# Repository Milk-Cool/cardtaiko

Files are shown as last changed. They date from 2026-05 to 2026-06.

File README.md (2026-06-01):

# card::taiko
osu!taiko simulator in a card form-factor!

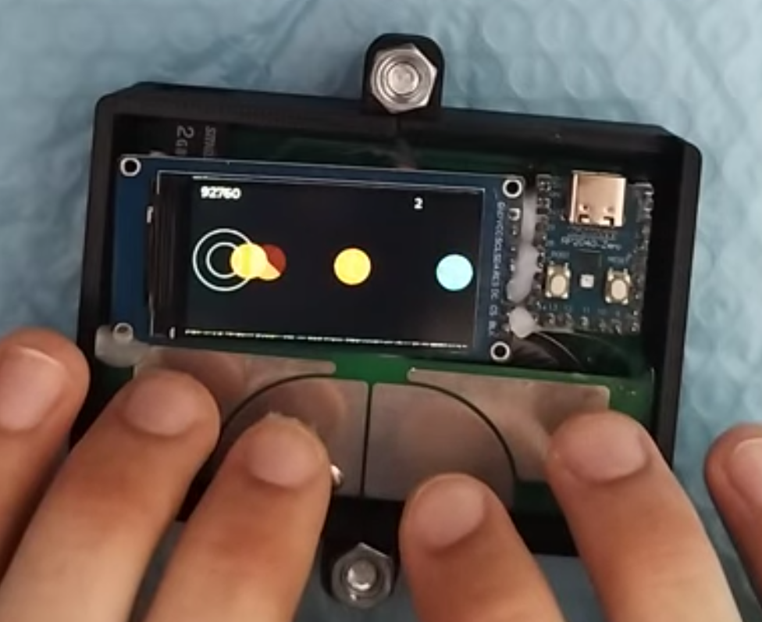
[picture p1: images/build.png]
card::taiko IRL


## what this is
this is an RP2040-Zero based device that is made for simulating osu!taiko as closely as i was able to make it. it comes with capacitive touch buttons specifically shaped for taiko, a 320x170 display, an SD card reader, a speaker and a battery. you can also emulate a keyboard to play taiko-based games on your PC.

## how do i use it?
you'll have to build one yourself!! you can see `bom.xml` for the list of parts, and all the PCBs and modelsn as well as the firmware can also be found in this repository. then, you can convert and upload songs to an sd card using the [online tool](https://milk-cool.github.io/cardtaiko/). you have to put the songs in `/taiko` on the SD card. then, boot up the device, select your song and have fun!! (you can pause at any time by pressing BOOTSEL on the board.)

for navigation, you can use the outer buttons to switch between options, the inner left one to go back and the inner right one to select.

### building it
there are a few unmarked headers on the pcb. the one closest to the RP2040-Zero is where the display goes, the one in the upper left corner is for the SD card reader, and the four small ones all around the bottom part are where the 1x1 headers go in for the capacitive touch board. speaking of which, you also have to solder in 4 1MOhm resistors near the pins so that capactive touch works.

> important: see the touch board to make sure everything lines up!!

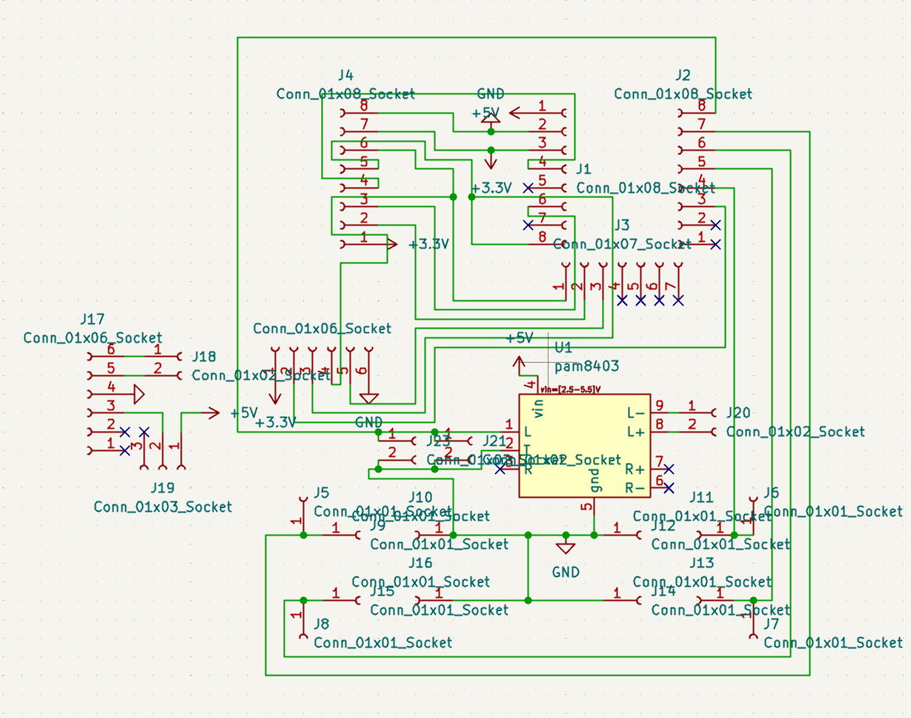
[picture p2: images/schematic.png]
the schematic

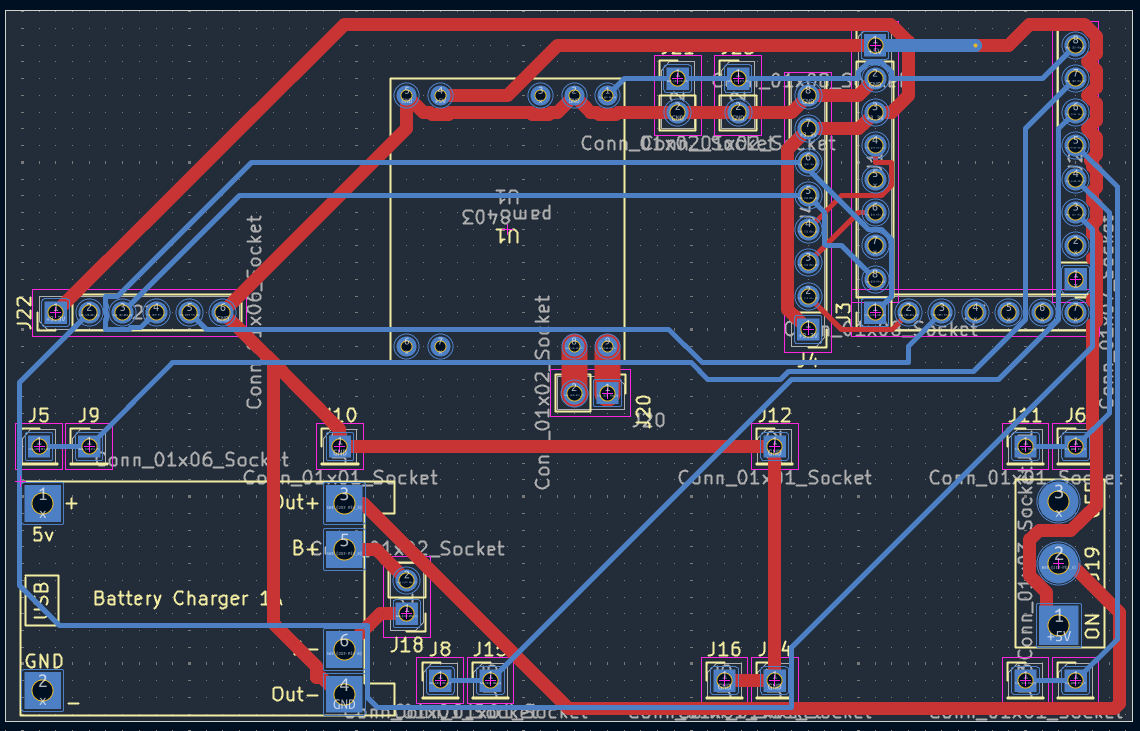
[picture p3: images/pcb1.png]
the main PCB

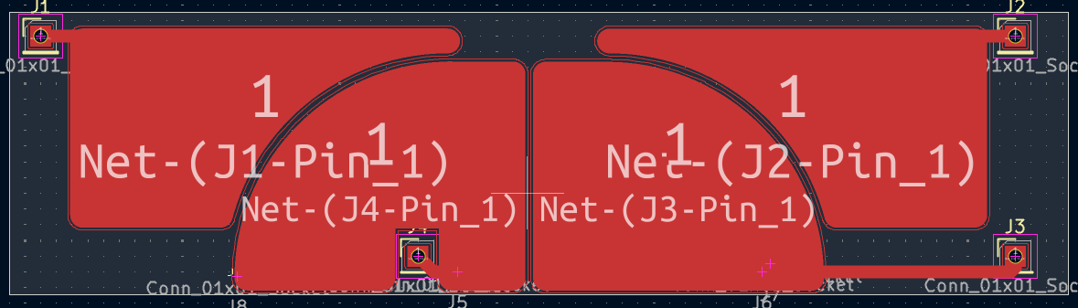
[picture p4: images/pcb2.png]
the touch PCB


### using the website
the interface is very simple: upload your .osz files, wait for the button to become active (that means that [ffmpeg](https://ffmpeg.org/) has loaded) and click convert!! evrything happens in your browser so it shouldn't take too long to finish.

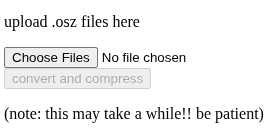
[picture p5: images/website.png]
the website UI


## why this was made
i am a huge fan of both taiko no tatsujin and osu!taiko, and also the [cardputer](https://shop.m5stack.com/products/m5stack-cardputer-adv-version-esp32-s3), which is why i decided it might be a fun idea to make a device that would let you play taiko on the go. and i also thought people might find the idea interesting as well :D

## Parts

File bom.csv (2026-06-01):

Product name | Product link | Product cost | Product amount | Notes
1 MOhm resistor | https://www.aliexpress.us/item/3256811699109203.html | $0.1 | 4 | Link leads to listing with 100 pieces available only. Price specified per unit; it is $0.99 to buy 100 pcs.
800 mAh lithium-ion battery | https://www.aliexpress.us/item/3256809268727485.html | $5.90 | 1
320x170 ST7789-based display | https://www.aliexpress.us/item/3256809447261733.html | $9.26 | 1 | w/ headers
RP2040-Zero board | https://www.aliexpress.us/item/3256806910625941.html | $5.08 | 1 | w/ headers
6-pin microSD card reader module | https://www.aliexpress.us/item/3256806810831719.html | $2.43 | 1 | Despite the seller saying it's a "Mini SD card module" it is not. Order that one.
0.1 uF ceramic capactior | https://www.aliexpress.us/item/3256809085304078.html | $0.02 | 1 | Link leads to listing with 100 pieces available only. Price specified per unit; it is $2.01 to buy 100 pcs.
10 uF electrolytic capactior | https://www.aliexpress.us/item/3256806406676171.html | $0.04 | 1 | Link leads to listing with 50 pieces available only. Price specified per unit; it is $2.16 to buy 50 pcs.
7-pin female headers | https://www.aliexpress.us/item/2255801012106911.html | $0.16 | 1 | Link leads to listing with 10 pieces available only. Price specified per unit; it is $1.60 to buy 10 pcs.
8-pin female headers | https://www.aliexpress.us/item/2255801012106911.html | $0.17 | 3 | Link leads to listing with 10 pieces available only. Price specified per unit; it is $1.65 to buy 10 pcs.
4-pin female headers | https://www.aliexpress.us/item/2255801012106911.html | $0.14 | 1 | Needs to be seprated into 4 1-pin headers. Link leads to listing with 10 pieces available only. Price specified per unit; it is $1.43 to buy 10 pcs.
4-pin male headers | https://www.aliexpress.us/item/3256809915878159.html | $0.14 | 1 | Needs to be seprated into 4 1-pin headers. Link leads to listing with 10 pieces available only. Price specified per unit; it is $1.35 to buy 10 pcs.
PAM8403 audio module | https://www.aliexpress.us/item/2255799876757727.html | $1.10 | 1
TP4056 power supply module | https://www.aliexpress.us/item/3256806796593467.html | $1.77 | 1
4ohm 3W speaker | https://www.aliexpress.us/item/2251832673662858.html | $0.81 | 1 | Link leads to listing with 5 pieces available only. Price specified per unit; it is $4.02 to buy 5 pcs.
1P2T switch | https://www.aliexpress.us/item/3256809760123375.html | $0.10 | 1 | Link leads to listing with 20 pieces available only. Price specified per unit; it is $2.00 to buy 20 pcs.

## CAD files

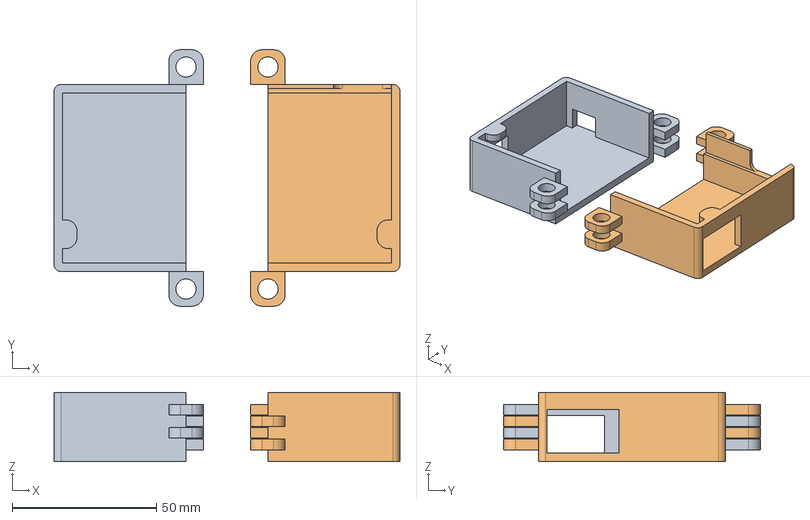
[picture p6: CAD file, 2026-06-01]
case/cardtaiko.step
120.0 x 89.0 x 24.0 mm

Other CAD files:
case/cardtaiko.FCStd
case/cardtaiko.obj

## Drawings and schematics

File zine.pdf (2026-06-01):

# card::taiko

## a credit card-sized osu!taiko

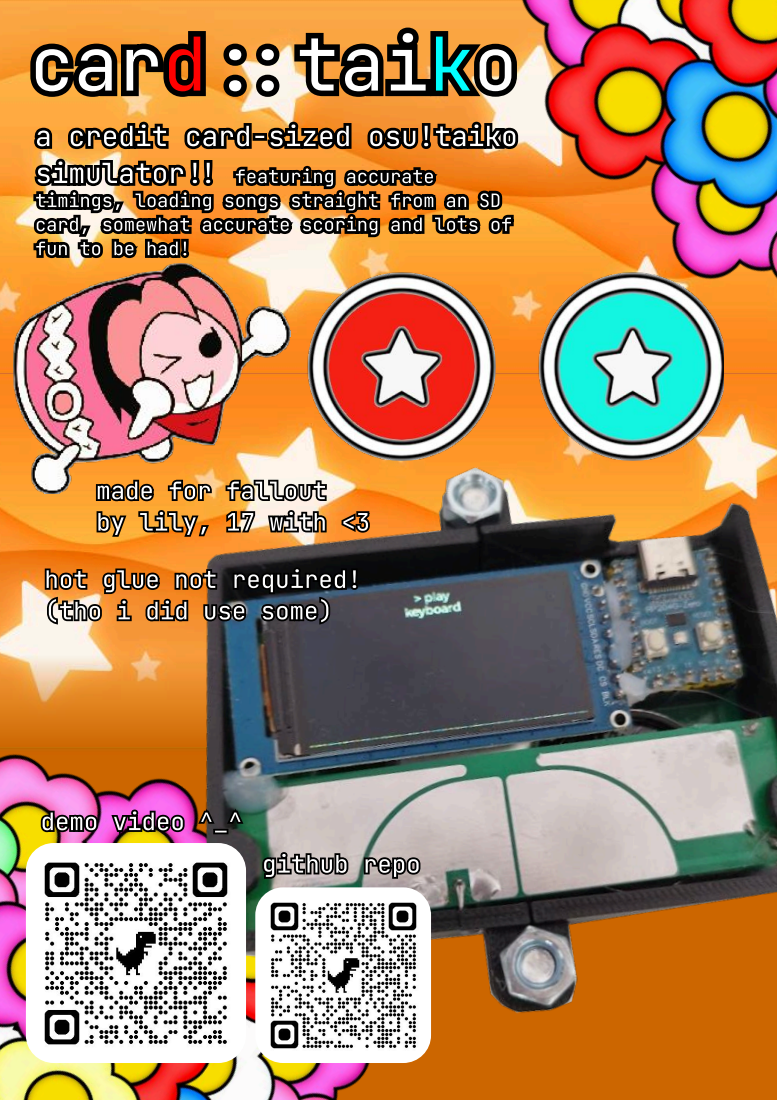
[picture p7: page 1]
demo video ^_^; github repo

simulator!! featuring accurate

timings, loading songs straight from an SD
card, somewhat accurate scoring and lots of
fun to be had!

made for fallout
by lily, 17 with <3

hot glue not required!
(tho i did use some)

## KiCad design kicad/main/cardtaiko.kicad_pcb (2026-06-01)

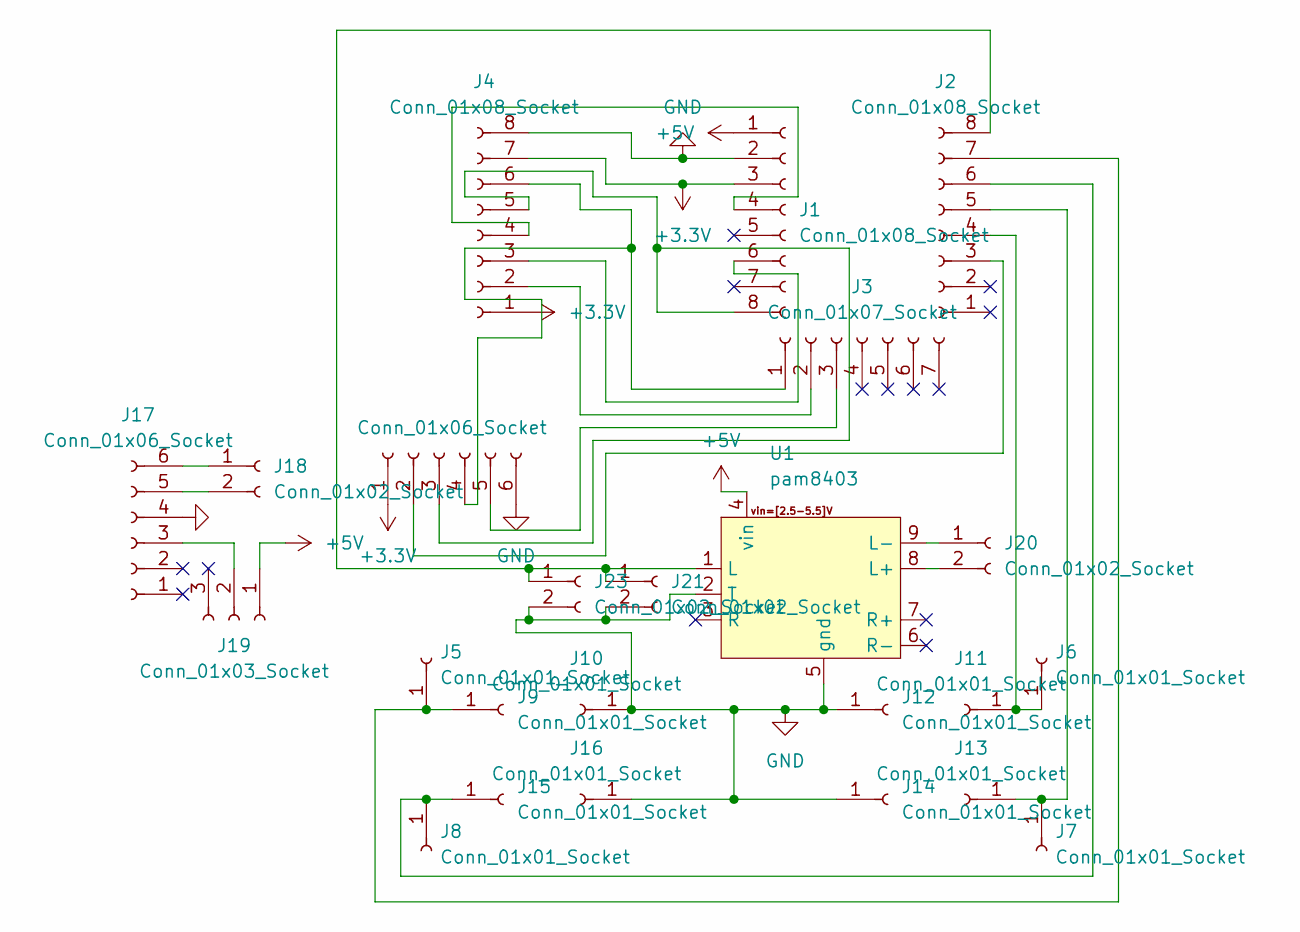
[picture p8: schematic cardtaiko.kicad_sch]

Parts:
J1, J2, J4: Conn_01x08_Socket; PinHeader_1x08_P2.54mm_Vertical
J3: Conn_01x07_Socket; PinHeader_1x07_P2.54mm_Vertical
J5, J6, J7, J8, J9, J10, J11, J12, J13, J14, J15, J16: Conn_01x01_Socket; PinHeader_1x01_P2.54mm_Vertical
J17: Conn_01x06_Socket; TP4056-18650
J18, J20, J21, J23: Conn_01x02_Socket; PinHeader_1x02_P2.54mm_Vertical
J19: Conn_01x03_Socket; 1p2t
J22: Conn_01x06_Socket; PinHeader_1x06_P2.54mm_Vertical
U1: pam8403

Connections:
+3.3V: J1.3, J4.1, J4.7, J22.1
+5V: J1.1, J19.1, U1.4 (vin)
GND: J1.2, J4.8, J10.1 (Pin_1_1), J12.1 (Pin_1_1), J14.1 (Pin_1_1), J16.1 (Pin_1_1), J17.4, J21.2, J22.6, J23.2, U1.2 (T), U1.5 (gnd)
unnamed: J1.4, J4.4
unnamed: J1.6, J4.3
unnamed: J1.8, J4.5, J22.3
unnamed: J2.3, J22.2
unnamed: J2.7, J5.1 (Pin_1_1), J9.1 (Pin_1_1)
unnamed: J2.8, J21.1, J23.1, U1.1 (L)
unnamed: J3.2, J4.2
unnamed: J2.4, J6.1 (Pin_1_1), J11.1 (Pin_1_1)
unnamed: J2.5, J7.1 (Pin_1_1), J13.1 (Pin_1_1)
unnamed: J2.6, J8.1 (Pin_1_1), J15.1 (Pin_1_1)
unnamed: J17.3, J19.2
unnamed: J17.5, J18.2
unnamed: J17.6, J18.1
unnamed: J20.1, U1.9 (L-)
unnamed: J20.2, U1.8 (L+)
unnamed: J3.1, J4.6, J22.4
unnamed: J3.3, J22.5

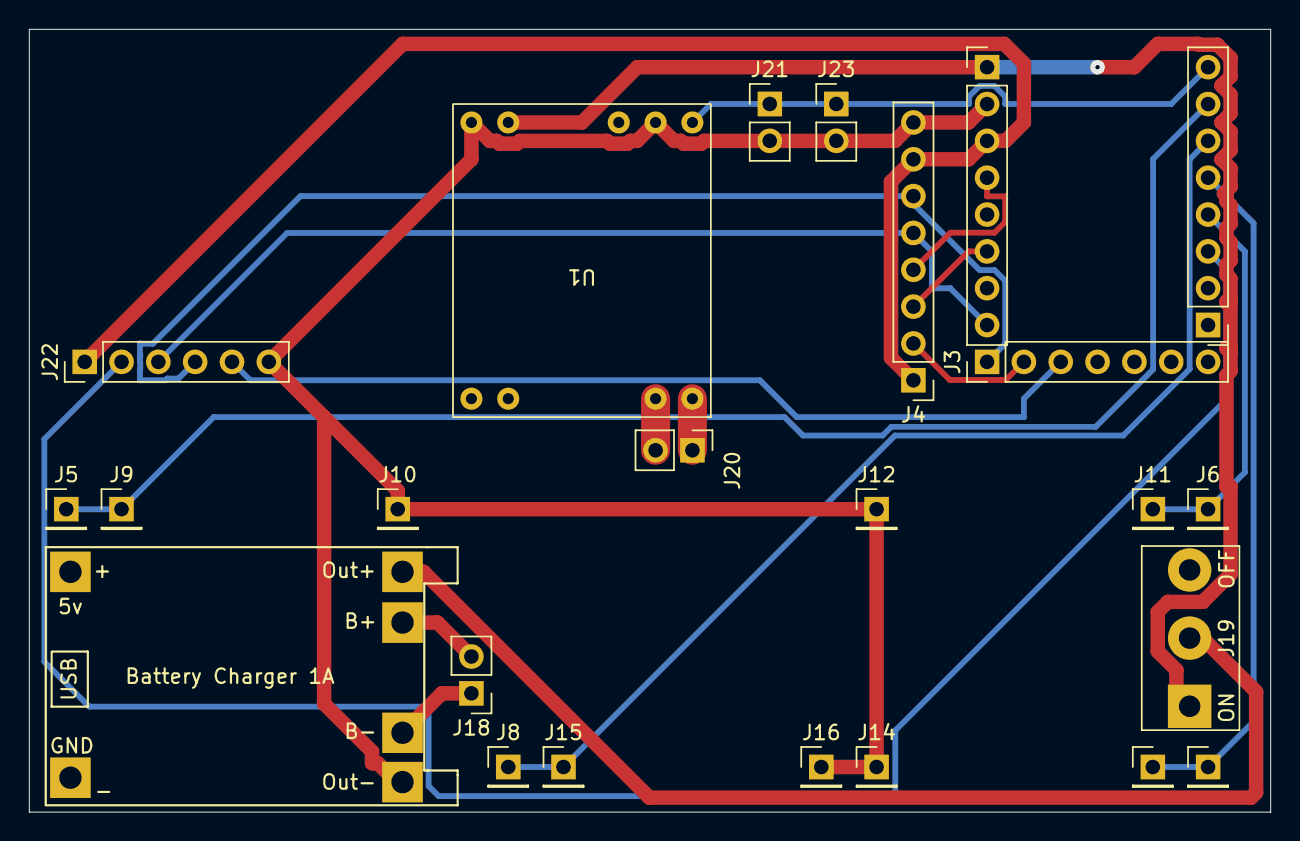
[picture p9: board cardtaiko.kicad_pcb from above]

Board: 2 copper layers, 85.6 x 54.0 mm, 24 parts (0 on the bottom side), 20 nets.

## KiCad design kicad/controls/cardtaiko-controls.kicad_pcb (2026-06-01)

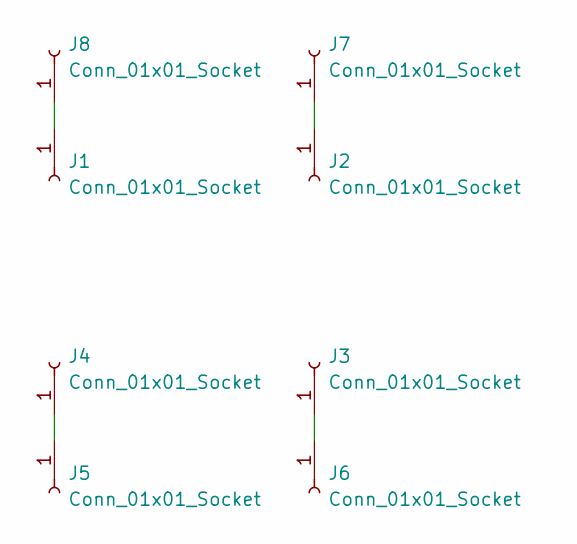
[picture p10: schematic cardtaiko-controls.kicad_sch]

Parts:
J1, J2, J3, J4: Conn_01x01_Socket; PinHeader_1x01_P2.54mm_Vertical
J5: Conn_01x01_Socket; Don Left
J6: Conn_01x01_Socket; Don Right
J7: Conn_01x01_Socket; Kat Right
J8: Conn_01x01_Socket; Kat Left

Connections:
unnamed: J1.1 (Pin_1_1), J8.1 (Pin_1_1)
unnamed: J2.1 (Pin_1_1), J7.1 (Pin_1_1)
unnamed: J3.1 (Pin_1_1), J6.1 (Pin_1_1)
unnamed: J4.1 (Pin_1_1), J5.1 (Pin_1_1)

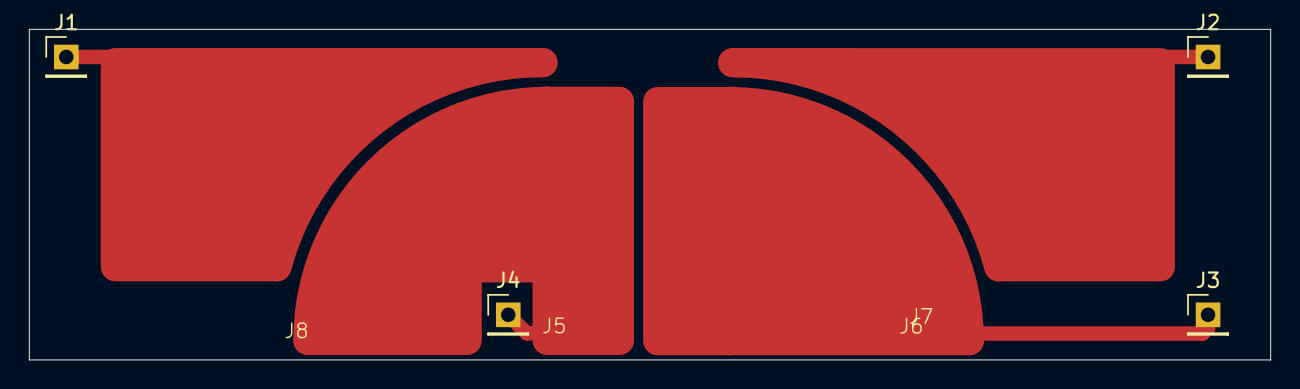
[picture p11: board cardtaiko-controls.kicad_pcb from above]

Board: 2 copper layers, 85.6 x 22.8 mm, 8 parts (0 on the bottom side), 4 nets.

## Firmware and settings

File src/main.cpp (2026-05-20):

#include <Arduino.h>
#include <LovyanGFX.hpp>
#include <SPI.h>
#include "lvcfg.h"
#include <lvgl.h>
#include "maps.h"
#include "input.h"
#include "en.h"
#include "audio.h"
#include <NeoPixelConnect.h>
#include <Keyboard.h>

#define W 320
#define H 170

static lv_disp_draw_buf_t draw_buf;
static lv_color_t buf[2][W * 10]; // what.

static bool simple_rendering = false;

static NeoPixelConnect p(16, 1);

class LGFX : public lgfx::LGFX_Device {
    lgfx::Panel_ST7789 _panel_instance;
    lgfx::Bus_SPI _bus_instance;

public:
    // https://garrysblog.com/2025/11/10/lovyangfx-display-config-code-ili9341-gc9a01-and-st7789-displays/
    LGFX() {
        {
            auto cfg = _bus_instance.config();
            cfg.spi_host = 1;
            cfg.spi_mode = 0;
            cfg.freq_write = 640000000; // how does this work???
            cfg.freq_read = 10000000;
            cfg.pin_sclk = 14;
            cfg.pin_mosi = 15;
            cfg.pin_miso = 12;
            cfg.pin_dc = 27;
            _bus_instance.config(cfg);
            _panel_instance.setBus(&_bus_instance);
        }
        {
            auto cfg = _panel_instance.config();
            cfg.pin_cs = 13;
            cfg.pin_rst = 29;
            cfg.pin_busy = -1;
            cfg.panel_width = H; // swapped bc display is rotated
            cfg.panel_height = W;
            cfg.offset_x = 34;
            cfg.offset_y = 0;
            cfg.offset_rotation = 0;
            cfg.dummy_read_pixel = 8;
            cfg.dummy_read_bits = 1;
            cfg.readable = false;
            cfg.invert = true;
            cfg.rgb_order = false;
            cfg.dlen_16bit = false;
            cfg.bus_shared = false;
            _panel_instance.config(cfg);
        }

        setPanel(&_panel_instance);
    }
};

LGFX tft = LGFX();

// https://github.com/lovyan03/LovyanGFX/blob/master/examples/Advanced/LVGL_PlatformIO/src/main.cpp#L17
void flush_gfx(lv_disp_drv_t* disp, const lv_area_t* area, lv_color_t* color_p) {
    if(tft.getStartCount() == 0)
        tft.startWrite();
    // hah. screw you google. screw you chatgpt. rgb565_t instead of swap565_t was the fix. and not even uint16_t. not even anything in lvcfg.h. hahah.
    tft.pushImageDMA(area->x1, area->y1, area->x2 - area->x1 + 1, area->y2 - area->y1 + 1, (lgfx::rgb565_t*)&color_p->full);
    tft.endWrite();
    lv_disp_flush_ready(disp);
}

static String filename(String path) {
    auto idx = path.lastIndexOf('/');
    if(idx == path.length() - 1) idx = path.substring(0, path.length() - 1).lastIndexOf('/');
    return path.substring(idx + 1);
}
static String diffname(String filename) {
    return filename.substring(filename.indexOf('[') + 1, filename.indexOf(']'));
}

static uint64_t game_start = 0;
static uint64_t pause_start;
static uint8_t menu_state = 0;
static bool use_diffname = false;
#define MENU_MAIN 0
#define MENU_LEVEL 1
#define MENU_DIFF 2
#define MENU_GAME 3
#define MENU_PAUSE 4
#define MENU_RESULTS 5
#define MENU_KEYBOARD 6
static std::vector<String> menu_options;
static unsigned menu_idx;
static String level_path;

Level lvl(""); // dummy level, we'll load the actual thing later on
lv_obj_t* score;
lv_obj_t* combo;
lv_obj_t* rating;
lv_obj_t* delta;
lv_obj_t* circles[2];
lv_obj_t* menu;
std::vector<lv_obj_t*> past;

static bool recalibrated = false;

static void menu_main() {
    menu_state = MENU_MAIN;
    menu_options.clear();
    menu_idx = 0;

    menu_options.push_back("play");
    menu_options.push_back("keyboard");
    // TODO
}
static void menu_level() {
    menu_state = MENU_LEVEL;
    menu_options.clear();
    menu_idx = 0;

    esd();
    maps_init();
    auto levels = maps_list();
    for(auto level : levels)
        menu_options.push_back(filename(level));
    maps_deinit();
    etft();
}
static void menu_diff() {
    menu_state = MENU_DIFF;
    menu_options.clear();
    menu_idx = 0;

    use_diffname = true;

    esd();
    maps_init();
    auto diffs = difficulty_list(level_path);
    for(auto diff : diffs)
        menu_options.push_back(filename(diff));
    maps_deinit();
    etft();
}
static void game_hide() {
    lv_obj_set_style_opa(score, LV_OPA_0, 0);
    lv_obj_set_style_opa(combo, LV_OPA_0, 0);
    lv_obj_set_style_opa(rating, LV_OPA_0, 0);
    lv_obj_set_style_opa(delta, LV_OPA_0, 0);
    lv_obj_set_style_opa(circles[0], LV_OPA_0, 0);
    lv_obj_set_style_opa(circles[1], LV_OPA_0, 0);
    lv_obj_set_style_opa(menu, LV_OPA_100, 0);
}
static void game_show() {
    lv_obj_set_style_opa(score, LV_OPA_100, 0);
    lv_obj_set_style_opa(combo, LV_OPA_100, 0);
    lv_obj_set_style_opa(rating, LV_OPA_100, 0);
    lv_obj_set_style_opa(delta, LV_OPA_100, 0);
    lv_obj_set_style_opa(circles[0], LV_OPA_100, 0);
    lv_obj_set_style_opa(circles[1], LV_OPA_100, 0);
    lv_obj_set_style_opa(menu, LV_OPA_0, 0);
}
static void menu_pause() {
    menu_state = MENU_PAUSE;
    menu_options.clear();
    menu_idx = 0;

    game_hide();
    menu_options.push_back("resume");
    menu_options.push_back("exit");

    for(auto x : past)
        lv_obj_del(x);
    past.clear();
}
static void menu_results() {
    menu_state = MENU_RESULTS;
    menu_options.clear();
    menu_idx = 0;

    game_hide();
    menu_options.push_back("GREAT: " + String(lvl.great));
    menu_options.push_back("OK: " + String(lvl.ok));
    menu_options.push_back("MISS: " + String(lvl.miss));
    menu_options.push_back("COMBO: " + String(lvl.combo));
    menu_options.push_back("MAX COMBO: " + String(lvl.maxcombo));
    menu_options.push_back("SCORE: " + String(lvl.score));
    menu_options.push_back("exit");

    for(auto x : past)
        lv_obj_del(x);
    past.clear();

    audio_stop();
}
static void menu_keyboard() {
    menu_state = MENU_KEYBOARD;
    menu_options.clear();
    menu_idx = 0;

    Keyboard.begin();
}
void setup() {
    // Serial.begin(115200); // no serial bc speaker

    audio_init();
    init_input();

    etft();
    tft.init();
    tft.setRotation(3);
    lv_init();
    lv_disp_draw_buf_init(&draw_buf, buf[0], buf[1], W * 10);

    // https://github.com/lovyan03/LovyanGFX/blob/master/examples/Advanced/LVGL_PlatformIO/src/main.cpp#L67
    static lv_disp_drv_t disp_drv;
    lv_disp_drv_init(&disp_drv);
    disp_drv.hor_res = W;
    disp_drv.ver_res = H;
    disp_drv.flush_cb = flush_gfx;
    disp_drv.draw_buf = &draw_buf;
    lv_disp_drv_register(&disp_drv);

    lv_obj_clear_flag(lv_scr_act(), LV_OBJ_FLAG_SCROLLABLE);
    lv_obj_set_style_bg_color(lv_scr_act(), lv_color_black(), 0);

    score = lv_label_create(lv_scr_act());
    lv_obj_set_x(score, 10);
    lv_obj_set_y(score, 0);
    lv_obj_set_style_text_color(score, lv_color_white(), 0);
    lv_label_set_text(score, "0");

    combo = lv_label_create(lv_scr_act());
    lv_obj_set_x(combo, 250);
    lv_obj_set_y(combo, 0);
    lv_obj_set_style_text_color(combo, lv_color_white(), 0);
    lv_label_set_text(combo, "0");

    rating = lv_label_create(lv_scr_act());
    lv_obj_set_x(rating, 15);
    lv_obj_set_y(rating, 17);
    lv_obj_set_style_text_align(rating, LV_TEXT_ALIGN_CENTER, 0);
    lv_obj_set_style_text_color(rating, lv_color_white(), 0);
    lv_obj_set_width(rating, 50);
    lv_label_set_text(rating, "");

    delta = lv_label_create(lv_scr_act());
    lv_obj_set_x(delta, 15);
    lv_obj_set_y(delta, 32);
    lv_obj_set_style_text_align(delta, LV_TEXT_ALIGN_CENTER, 0);
    lv_obj_set_style_text_color(delta, lv_color_white(), 0);
    lv_obj_set_width(delta, 50);
    lv_label_set_text(delta, "");

    menu = lv_label_create(lv_scr_act());
    lv_obj_set_x(menu, 0);
    lv_obj_set_y(menu, 0);
    lv_obj_set_style_text_align(menu, LV_TEXT_ALIGN_CENTER, 0);
    lv_obj_set_style_text_color(menu, lv_color_white(), 0);
    lv_obj_set_width(menu, W);
    lv_obj_set_height(menu, H);
    lv_label_set_text(menu, "");

    int j = 0;
    for(int i = 35; i >= 20; i -= 15) {
        lv_obj_t* circle = lv_obj_create(lv_scr_act());
        lv_obj_set_x(circle, 40 - i);
        lv_obj_set_y(circle, 170 / 2 - i);
        lv_obj_set_size(circle, 2 * i, 2 * i);
        lv_obj_set_style_radius(circle, LV_RADIUS_CIRCLE, 0);
        lv_obj_set_style_bg_color(circle, lv_color_black(), 0);
        lv_obj_set_style_bg_opa(circle, LV_OPA_COVER, 0);
        lv_obj_set_style_border_color(circle, lv_palette_main(LV_PALETTE_GREY), 0);
        lv_obj_set_style_border_width(circle, 2, 0);
        circles[j++] = circle;
    }

    menu_main();
    game_hide();
}
uint8_t last_mask = 0;
static void render_menu(uint8_t pressed) {
    if(check_input(pressed, INPUT_KAT_LEFT)) {
        if(menu_idx == 0) menu_idx = menu_options.size() - 1;
        else menu_idx--;
    } else if(check_input(pressed, INPUT_KAT_RIGHT)) {
        if(menu_idx == menu_options.size() - 1) menu_idx = 0;
        else menu_idx++;
    }

    unsigned start = (menu_idx / 10) * 10;
    std::vector<String> sel_options;
    for(unsigned i = start; i < menu_options.size() && i < start + 10; i++)
        sel_options.push_back(menu_options[i]);
    String o = "";
    for(int i = 0; i < sel_options.size(); i++)
        o += (i == menu_idx - start ? "> " : "") + (use_diffname ? diffname(sel_options[i]) : sel_options[i]) + "\n";
    lv_label_set_text(menu, o.c_str());
}
static void loop_main(uint8_t pressed) {
    render_menu(pressed);

    if(check_input(pressed, INPUT_DON_RIGHT)) {
        String& sel = menu_options[menu_idx];
        if(sel == "play") menu_level();
        else if(sel == "keyboard") menu_keyboard();
    }
}
static void loop_level(uint8_t pressed) {
    render_menu(pressed);

    if(check_input(pressed, INPUT_DON_RIGHT)) {
        String& sel = menu_options[menu_idx];
        level_path = "/taiko/" + sel;
        menu_diff();
    } else if(check_input(pressed, INPUT_DON_LEFT))
        menu_main();
}
static void loop_diff(uint8_t pressed) {
    render_menu(pressed);

    if(check_input(pressed, INPUT_DON_RIGHT)) {
        use_diffname = false;
        String& sel = menu_options[menu_idx];
        esd();
        maps_init();
        lvl = load_level(level_path + "/" + sel);
        maps_deinit();
        etft();
        audio_play(level_path + "/");
        game_start = 0;
        menu_state = MENU_GAME;
        recalibrated = false;
        game_show();
    } else if(check_input(pressed, INPUT_DON_LEFT)) {
        use_diffname = false;
        menu_level();
    }
}
static void loop_game(uint8_t pressed) {
    if(millis() < game_start) return;

    if(!recalibrated && millis() - game_start >= 150) {
        recalibrated = true;
        recalibrate_input();
    }

    if(check_input(pressed, INPUT_BOOTSEL)) {
        pause_start = millis();
        menu_pause();

        return;
    }

    lvl.btn(millis() - game_start, pressed);

    for(auto x : past)
        lv_obj_del(x);
    past.clear();
    auto cur = lvl.render(millis() - game_start);
    if(cur.fin) {
        lvl.fin();
        menu_results();
        return;
    }
    for(auto x : cur.objs) {
        int r = x.big ? 35 : 20;
        auto c = x.type & 8 ? LV_PALETTE_INDIGO : x.type & 2 ? LV_PALETTE_YELLOW : x.kat ? LV_PALETTE_CYAN : LV_PALETTE_RED;

        lv_obj_t* circle = lv_obj_create(lv_scr_act());
        lv_obj_set_x(circle, x.x - r);
        lv_obj_set_y(circle, 170 / 2 - r);
        lv_obj_set_size(circle, 2 * r + x.len, 2 * r);
        lv_obj_set_style_radius(circle, r, 0);
        lv_obj_set_style_bg_color(circle, lv_palette_main(c), 0);
        lv_obj_set_style_bg_opa(circle, simple_rendering ? LV_OPA_TRANSP : LV_OPA_COVER, 0);
        lv_obj_set_style_border_width(circle, simple_rendering ? 2 : 0, 0);
        lv_obj_set_style_border_color(circle, lv_palette_main(c), 0);
        past.push_back(circle);
    }
    
    auto rat = lvl.get_rating(millis() - game_start);
    lv_label_set_text(rating, rat.txt.c_str());
    lv_label_set_text(delta, rat.delta.c_str());
    lv_obj_set_style_text_opa(rating, rat.opacity * 255, 0);
    lv_obj_set_style_text_opa(delta, rat.opacity * 255, 0);

    lv_label_set_text(score, String(lvl.score).c_str());
    lv_label_set_text(combo, String(lvl.combo).c_str());
}
static void loop_pause(uint8_t pressed) {
    render_menu(pressed);

    if(check_input(pressed, INPUT_DON_RIGHT)) {
        String& sel = menu_options[menu_idx];
        if(sel == "exit") {
            audio_stop();
            menu_main();
        } else if(sel == "resume") {
            game_show();
            game_start += millis() - pause_start;
            menu_state = MENU_GAME;
            menu_options.clear();
        }
    }
}
static void loop_results(uint8_t pressed) {
    render_menu(pressed);

    if(check_input(pressed, INPUT_DON_RIGHT)) {
        String& sel = menu_options[menu_idx];
        if(sel == "exit") {
            delay(150); // lazy fix
            recalibrate_input();
            menu_main();
        }
    }
}
static void loop_keyboard(uint8_t held) {
    render_menu(0);

    if(check_input(held, INPUT_KAT_LEFT)) Keyboard.press('d');
    else Keyboard.release('d');
    if(check_input(held, INPUT_DON_LEFT)) Keyboard.press('f');
    else Keyboard.release('f');
    if(check_input(held, INPUT_DON_RIGHT)) Keyboard.press('j');
    else Keyboard.release('j');
    if(check_input(held, INPUT_KAT_RIGHT)) Keyboard.press('k');
    else Keyboard.release('k');
    if(check_input(held, INPUT_BOOTSEL)) {
        Keyboard.end();
        menu_main();
    }
}
uint64_t last = 0;
void loop() {
    if(menu_state == MENU_GAME) {
        audio_loop();
        if(game_start == 0) game_start = millis() + 10; // compensate for the audio offset
    }

    uint8_t mask = get_input();
    bool don = check_input(mask, INPUT_DON_LEFT) || check_input(mask, INPUT_DON_RIGHT);
    bool kat = check_input(mask, INPUT_KAT_LEFT) || check_input(mask, INPUT_KAT_RIGHT);
    // use 40 for dimmer led
    if(don && kat) p.neoPixelSetValue(0, 40, 40, 0, true);
    else if(kat) p.neoPixelSetValue(0, 0, 40, 40, true);
    else if(don) p.neoPixelSetValue(0, 40, 0, 0, true);
    else p.neoPixelSetValue(0, 0, 0, 0, true);

    uint8_t pressed = (mask ^ last_mask) & mask;
    // if(check_input(pressed, INPUT_DON_RIGHT)) Serial.println("DON_RIGHT");
    // if(check_input(pressed, INPUT_DON_LEFT)) Serial.println("DON_LEFT");
    // if(check_input(pressed, INPUT_KAT_RIGHT)) Serial.println("KAT_RIGHT");
    // if(check_input(pressed, INPUT_KAT_LEFT)) Serial.println("KAT_LEFT");
    // if(check_input(pressed, INPUT_BOOTSEL)) Serial.println("BOOTSEL");
    last_mask = mask;

    if(menu_state == MENU_MAIN)
        loop_main(pressed);
    else if(menu_state == MENU_LEVEL)
        loop_level(pressed);
    else if(menu_state == MENU_DIFF)
        loop_diff(pressed);
    else if(menu_state == MENU_GAME)
        loop_game(pressed);
    else if(menu_state == MENU_PAUSE)
        loop_pause(pressed);
    else if(menu_state == MENU_RESULTS)
        loop_results(pressed);
    else if(menu_state == MENU_KEYBOARD)
        loop_keyboard(mask);

    lv_refr_now(lv_disp_get_default());
    lv_timer_handler();
}

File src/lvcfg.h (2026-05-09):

/**
 * @file lv_conf.h
 * Configuration file for v8.3.0-dev
 */

/*
 * Copy this file as `lv_conf.h`
 * 1. simply next to the `lvgl` folder
 * 2. or any other places and
 *    - define `LV_CONF_INCLUDE_SIMPLE`
 *    - add the path as include path
 */

/* clang-format off */
#if 1 /*Set it to "1" to enable content*/

#ifndef LV_CONF_H
#define LV_CONF_H

#include <stdint.h>

/*====================
   COLOR SETTINGS
 *====================*/

/*Color depth: 1 (1 byte per pixel), 8 (RGB332), 16 (RGB565), 32 (ARGB8888)*/
#define LV_COLOR_DEPTH 16

/*Swap the 2 bytes of RGB565 color. Useful if the display has an 8-bit interface (e.g. SPI)*/
#define LV_COLOR_16_SWAP 0

/*Enable more complex drawing routines to manage screens transparency.
 *Can be used if the UI is above another layer, e.g. an OSD menu or video player.
 *Requires `LV_COLOR_DEPTH = 32` colors and the screen's `bg_opa` should be set to non LV_OPA_COVER value*/
#define LV_COLOR_SCREEN_TRANSP 0

/* Adjust color mix functions rounding. GPUs might calculate color mix (blending) differently.
 * 0: round down, 64: round up from x.75, 128: round up from half, 192: round up from x.25, 254: round up */
#define LV_COLOR_MIX_ROUND_OFS (LV_COLOR_DEPTH == 32 ? 0: 128)

/*Images pixels with this color will not be drawn if they are chroma keyed)*/
#define LV_COLOR_CHROMA_KEY lv_color_hex(0x00ff00)         /*pure green*/

/*=========================
   MEMORY SETTINGS
 *=========================*/

/*1: use custom malloc/free, 0: use the built-in `lv_mem_alloc()` and `lv_mem_free()`*/
#define LV_MEM_CUSTOM 0
#if LV_MEM_CUSTOM == 0
    /*Size of the memory available for `lv_mem_alloc()` in bytes (>= 2kB)*/
    #define LV_MEM_SIZE (48U * 1024U)          /*[bytes]*/

    /*Set an address for the memory pool instead of allocating it as a normal array. Can be in external SRAM too.*/
    #define LV_MEM_ADR 0     /*0: unused*/
    /*Instead of an address give a memory allocator that will be called to get a memory pool for LVGL. E.g. my_malloc*/
    #if LV_MEM_ADR == 0
        //#define LV_MEM_POOL_INCLUDE your_alloc_library  /* Uncomment if using an external allocator*/
        //#define LV_MEM_POOL_ALLOC   your_alloc          /* Uncomment if using an external allocator*/
    #endif

#else       /*LV_MEM_CUSTOM*/
    #define LV_MEM_CUSTOM_INCLUDE <stdlib.h>   /*Header for the dynamic memory function*/
    #define LV_MEM_CUSTOM_ALLOC   malloc
    #define LV_MEM_CUSTOM_FREE    free
    #define LV_MEM_CUSTOM_REALLOC realloc
#endif     /*LV_MEM_CUSTOM*/

/*Number of the intermediate memory buffer used during rendering and other internal processing mechanisms.
 *You will see an error log message if there wasn't enough buffers. */
#define LV_MEM_BUF_MAX_NUM 16

/*Use the standard `memcpy` and `memset` instead of LVGL's own functions. (Might or might not be faster).*/
#define LV_MEMCPY_MEMSET_STD 0

/*====================
   HAL SETTINGS
 *====================*/

/*Default display refresh period. LVG will redraw changed areas with this period time*/
#define LV_DISP_DEF_REFR_PERIOD 16      /*[ms]*/

/*Input device read period in milliseconds*/
#define LV_INDEV_DEF_READ_PERIOD 30     /*[ms]*/

/*Use a custom tick source that tells the elapsed time in milliseconds.
 *It removes the need to manually update the tick with `lv_tick_inc()`)*/
#define LV_TICK_CUSTOM 1
#if LV_TICK_CUSTOM
    #define LV_TICK_CUSTOM_INCLUDE "Arduino.h"         /*Header for the system time function*/
    #define LV_TICK_CUSTOM_SYS_TIME_EXPR (millis())    /*Expression evaluating to current system time in ms*/
#endif   /*LV_TICK_CUSTOM*/

/*Default Dot Per Inch. Used to initialize default sizes such as widgets sized, style paddings.
 *(Not so important, you can adjust it to modify default sizes and spaces)*/
#define LV_DPI_DEF 130     /*[px/inch]*/

/*=======================
 * FEATURE CONFIGURATION
 *=======================*/

/*-------------
 * Drawing
 *-----------*/

/*Enable complex draw engine.
 *Required to draw shadow, gradient, rounded corners, circles, arc, skew lines, image transformations or any masks*/
#define LV_DRAW_COMPLEX 1
#if LV_DRAW_COMPLEX != 0

    /*Allow buffering some shadow calculation.
    *LV_SHADOW_CACHE_SIZE is the max. shadow size to buffer, where shadow size is `shadow_width + radius`
    *Caching has LV_SHADOW_CACHE_SIZE^2 RAM cost*/
    #define LV_SHADOW_CACHE_SIZE 0

    /* Set number of maximally cached circle data.
    * The circumference of 1/4 circle are saved for anti-aliasing
    * radius * 4 bytes are used per circle (the most often used radiuses are saved)
    * 0: to disable caching */
    #define LV_CIRCLE_CACHE_SIZE 4
#endif /*LV_DRAW_COMPLEX*/

/*Default image cache size. Image caching keeps the images opened.
 *If only the built-in image formats are used there is no real advantage of caching. (I.e. if no new image decoder is added)
 *With complex image decoders (e.g. PNG or JPG) caching can save the continuous open/decode of images.
 *However the opened images might consume additional RAM.
 *0: to disable caching*/
#define LV_IMG_CACHE_DEF_SIZE   0

/*Number of stops allowed per gradient. Increase this to allow more stops.
 *This adds (sizeof(lv_color_t) + 1) bytes per additional stop*/
#define LV_GRADIENT_MAX_STOPS       2

/*Default gradient buffer size.
 *When LVGL calculates the gradient "maps" it can save them into a cache to avoid calculating them again.
 *LV_GRAD_CACHE_DEF_SIZE sets the size of this cache in bytes.
 *If the cache is too small the map will be allocated only while it's required for the drawing.
 *0 mean no caching.*/
#define LV_GRAD_CACHE_DEF_SIZE      0

/*Allow dithering the gradients (to achieve visual smooth color gradients on limited color depth display)
 *LV_DITHER_GRADIENT implies allocating one or two more lines of the object's rendering surface
 *The increase in memory consumption is (32 bits * object width) plus 24 bits * object width if using error diffusion */
#define LV_DITHER_GRADIENT      0
#if LV_DITHER_GRADIENT
    /*Add support for error diffusion dithering.
     *Error diffusion dithering gets a much better visual result, but implies more CPU consumption and memory when drawing.
     *The increase in memory consumption is (24 bits * object's width)*/
    #define LV_DITHER_ERROR_DIFFUSION   0
#endif

/*Maximum buffer size to allocate for rotation.
 *Only used if software rotation is enabled in the display driver.*/
#define LV_DISP_ROT_MAX_BUF (10*1024)

/*-------------
 * GPU
 *-----------*/

/*Use Arm's 2D acceleration library Arm-2D */
#define LV_USE_GPU_ARM2D 0

/*Use STM32's DMA2D (aka Chrom Art) GPU*/
#define LV_USE_GPU_STM32_DMA2D 0
#if LV_USE_GPU_STM32_DMA2D
    /*Must be defined to include path of CMSIS header of target processor
    e.g. "stm32f769xx.h" or "stm32f429xx.h"*/
    #define LV_GPU_DMA2D_CMSIS_INCLUDE
#endif
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

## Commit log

2026-05-09 switch to lgfx
2026-05-10 clearly, i am way too tired for this
2026-05-11 fix bug with level loading
    [main.cpp]
2026-05-13 it just doesn't work :(( i'm still gonna commit everything tho
    [audio.cpp, main.cpp]
2026-05-14 capacitive touch, audio rewrite
2026-05-14 remove debug prints
2026-05-15 :yay: it works again!! and also added led support
2026-05-16 change led brigthness to 40
2026-05-17 a couple fixes
2026-05-20 a couple more firmware fixes
    [main.cpp]
2026-06-01 add BOM
    [bom.csv]
2026-06-01 add kicad files and 3d models
    [cardtaiko-controls.kicad_pcb, cardtaiko-controls.kicad_sch, cardtaiko.FCStd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]
